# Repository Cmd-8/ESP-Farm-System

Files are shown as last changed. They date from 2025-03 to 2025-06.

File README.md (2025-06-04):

# ESP-Farm-System
Auto Farming System ESP-32

Read "ESP Auto Greenhouse Farm.pdf" for more detail

STL models for 3D printing 

Summary: 
This system is designed to automate watering, lighting, and sensor data collection 
for household or small community greenhouse farming. It can be easily monitored 
and controlled through any internet-connected device. Powered by four ESP-32 
devices, the system collects environmental data, processes it using moving 
averages and low-pass filters for accuracy, and sends this data to other devices to 
activate watering and lighting systems as needed. Users can customize the 
frequency of data collection, ranging from once a day to every 15 minutes, 
optimizing power usage based on plant care needs. The data is sent to Adafruit IO 
which graphs all data, this can be analyzed and be used to improve the system 
itself.  
  
The system includes four key ESP-32 units. SS.ESP handles sensor data collection 
and sends it to the rest of the system. H.ESP activates the watering system based 
on sensor readings, ensuring plants receive the correct amount of water. L.ESP 
manages the lighting system, providing the lights turn on at a fixed time each day. 
Sunflower tracks the sun's position by adjusting its motor to align with the azimuth 
and elevation of the sun, using monthly average data from a sun-tracking website. 
This feature makes the system self-sufficient. The 3D model design of sunflower 
has leaves sticking out from the stem similar to an actual sunflower.

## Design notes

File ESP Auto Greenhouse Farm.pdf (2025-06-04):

# E-Farm

## Summary:

This system is designed to automate watering, lighting, and sensor data collection for household or small community greenhouse farming. It can be easily monitored and controlled through any internet-connected device. Powered by four ESP-32 devices, the system collects environmental data, processes it using moving averages and low-pass filters for accuracy, and sends this data to other devices to activate watering and lighting systems as needed. Users can customize the frequency of data collection, ranging from once a day to every 15 minutes, optimizing power usage based on plant care needs. The data is sent to Adafruit IO which graphs all data, this can be analyzed and be used to improve the system itself.

The system includes four key ESP-32 units. SS.ESP handles sensor data collection and sends it to the rest of the system. H.ESP activates the watering system based on sensor readings, ensuring plants receive the correct amount of water. L.ESP manages the lighting system, providing the lights turn on at a fixed time each day. Sunflower tracks the sun's position by adjusting its motor to align with the azimuth and elevation of the sun, using monthly average data from a sun-tracking website. This feature makes the system self-sufficient. The 3D model design of sunflower has leaves sticking out from the stem similar to an actual sunflower.

Links
Code: https://github.com/Cmd-8/ESP-Farm-System
YouTube: www.youtube.com/@Cmd.8

## Parts:

4x ESP-32
1x BME280
2-5x Capacitive soil moisture sensor
1-2x Relay Module
1x Peristaltic Liquid Pump or 1x Plastic Water Solenoid Valve 1x l298n motor driver
1x Solar panel
2x waterproof Nema 17 or 23 motor
1x Power station or some form of power system 1x CNC Sheild and 2x DRV8825

## Method:

I will provide a tutorial video for all the customizing for all the different systems.

The case design for components should not be used exclusively for outdoor environments and must include additional protection. For example, a box to put the electronics in can be used alongside the case design to safeguard the components. The case design is intended for indoor use within a greenhouse, ideally placed in an elevated location. Users should be aware that thicker walls or certain materials may interfere with data transmission. 3D printed cases or parts should be using ASA material, as it provides heat and UV protection, preventing warping due to temperature changes or UV exposure.

When setting up the soil sensor, it is recommended to use larger sections of soil rather than multiple smaller ones for vegetables, maximizing the use of one sensor per type of vegetable. This approach works well because soil moisture doesn’t fluctuate significantly over short distances unless physically separated.

The water pump can source water from a rainwater recycling system or use a water valve. A relay or motor driver can be used to control the valve or pump, with a relay being the preferred option for this application. Set up a cup to measure how much water it gets for each timer setting.

To set up Adafruit, you must create an account with Adafruit, which will provide an API key. This key should be written into the code where specified. Wi-Fi information should also be configured, as outlined in the code. Both L.ESP and SS.ESP require both Adafruit and Wi-Fi connections, while H.ESP only requires Wi-Fi. S.ESP and H.ESP must have the same interval time to sync together. For example:

#define TIME_TO_SLEEP 900

This value represents 15 minutes in seconds. After the data is taken, the system will enter deep sleep for 15 minutes before repeating the process. Both must use the same value to remain synchronized.

The Sunflower system has a weight limit of 3.0 lbs for the solar panel from the X-motor. Users can obtain the sun path for their location from a website and average the monthly data. The code is designed for easy customization, allowing users to adjust settings as needed. 3D scanning the leaves and features on sunflowers can provide for a more realistic look!

L.ESP can be used with full spectrum light bulbs for additional light in seasons where there’s not a lot of sunlight, this allows vegetables to grow all year round. It uses a relay switch that enables and disables current flow to light bulbs. Light bulbs should be in parallel cause the light bulb in series will cause the voltage to go over the relay limit instead use parallel for amperes, the limit being 10A and I got around 4/6 light bulbs with it.

## Electrical Use:

The average cost for electrical power is 1kilowatts for $0.14.
The running time for SS.ESP is 1-2 milliseconds with ~600 milliamps/hour but deep-sleep uses 5-10 microamps, and always 5 volts.
H.ESP and L.ESP use around ~300 milliamps/hour when activated and the same deep sleep power consumption.

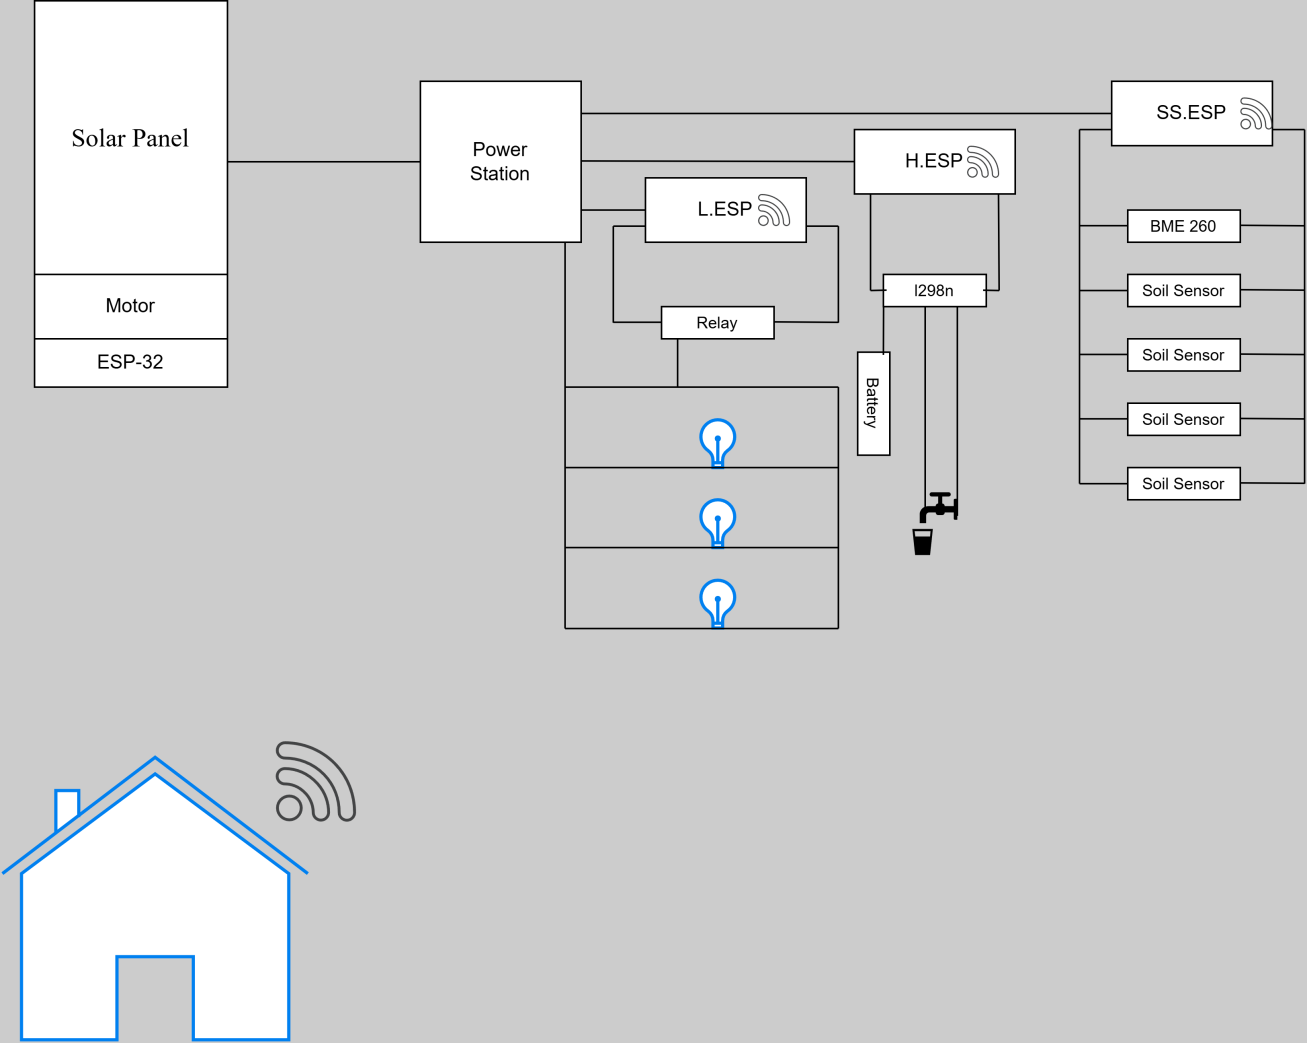
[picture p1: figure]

## Technical:

Communication between ESP-32 devices utilizes the ESP-NOW protocol, which relies on the MAC address of each device. It ensures 100% data transmission up to 220 meters, though it can extend to 1,000 meters with some data loss. The ESP data filter processes 10 sensor readings, averages them and applies a low-pass filter before sending the data. For more accurate results, you can increase the sample rate beyond 10 and adjust the low-pass filter by modifying the alpha value (0 < a < 1). Additional improvements can be made by using a hardware low-pass filter, applying EMI protection to the wires, and using an external 16-bit ADC for sensors.

Adafruit IO allows up to 30 data points per minute and 10 feeds (e.g., "Temperature feed") in the free version. The paid version increases this to 60 data points per minute and offers unlimited feeds, making it suitable for large-scale greenhouse farming. Adafruit also provides a graphical interface to display the data, enabling users to analyze trends and make improvements, which contributes to the system's self-improvement over time.

The sensors and lights are connected in parallel due to the low current draw of each device. Each relay typically supports a maximum load of AC 250V / 10A or DC 30V / 10A and can be used with 4-6 full-spectrum lights that promote plant growth. Capacitive soil sensors are preferred due to their reliability compared to other types that may rust over time. However, the exposed electronics on the top of the sensor should be protected with a 3D-printed case for enhanced durability.

The water valve can be powered by a power station or an external source such as a battery. The ESP-32 receives soil moisture data through the ESP-NOW protocol and can be customized to control watering based on specific plant requirements, using a timer (e.g., `Delay(1000)`).

The Sunflower system uses two waterproof Nema 17 stepper motors and a CNC Shield with two DRV8825 drivers. The power supply is 12/24V ~3A, which can be connected to an outlet, power station, or external battery. The Sunflower system activates every hour to move the two motors, with the X-motor adjusting the azimuth and the Y-motor controlling the elevation. The data averages the sun's position for azimuth and elevation each month. The system's accuracy has an error range of ±1.8 degrees, as each step is 1.8 degrees, and the stepper motor only moves in whole steps, rounding the values during calculation.

The weight limit for the solar panel on the X-motor is 3.0 lbs, lighter panels reduce power consumption, as less torque is required to move the panel. Lower torque means less current is needed to move the motor. To accommodate a heavier solar panel, the acceleration and speed can be adjusted to provide more torque.

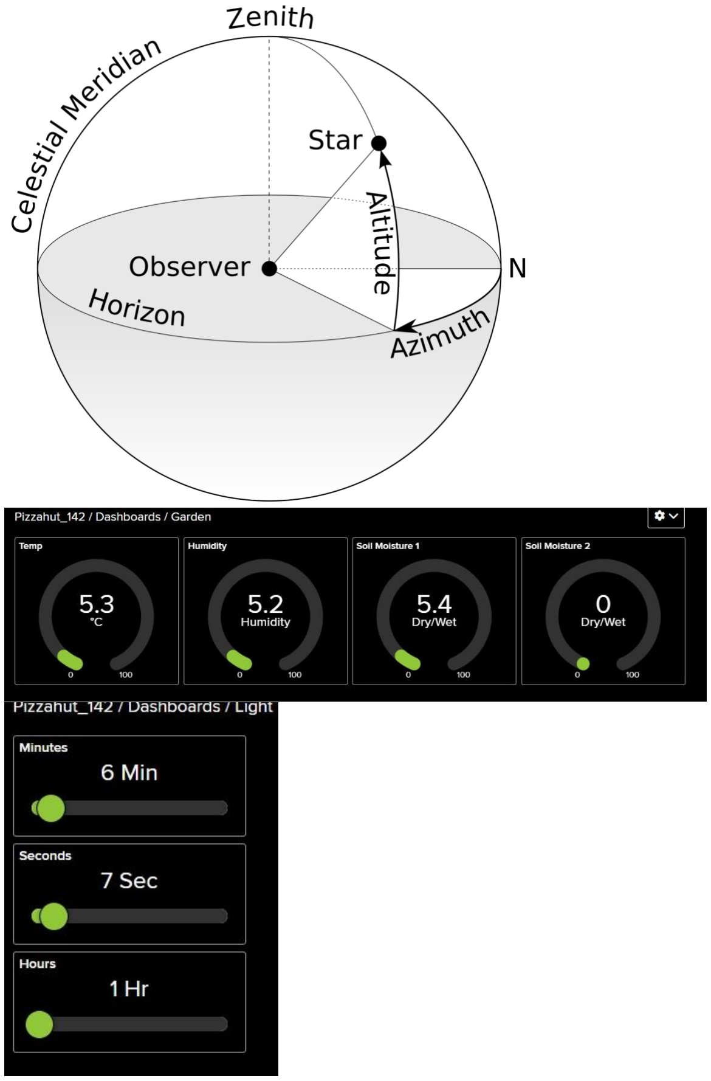
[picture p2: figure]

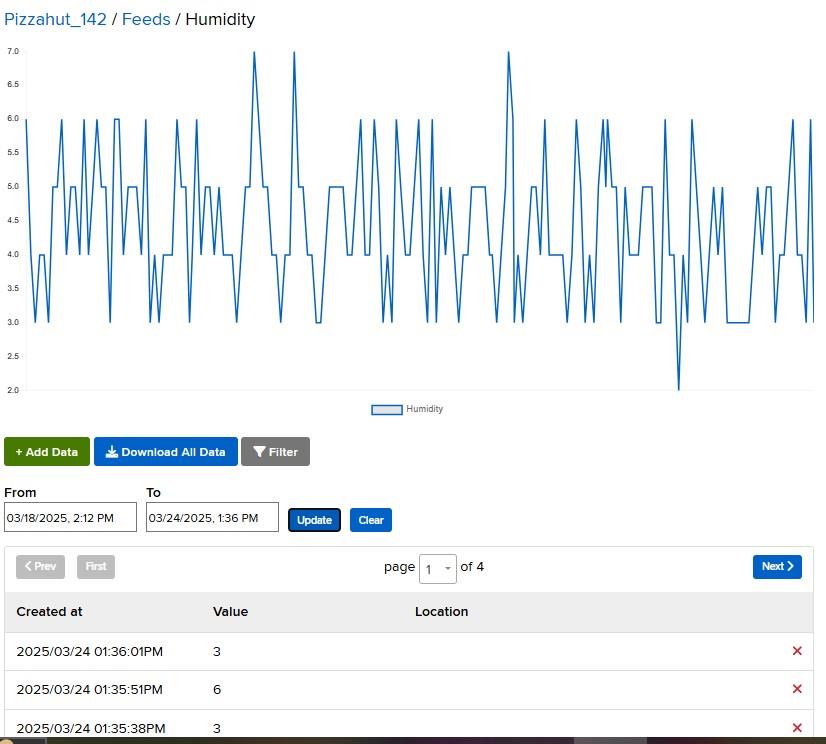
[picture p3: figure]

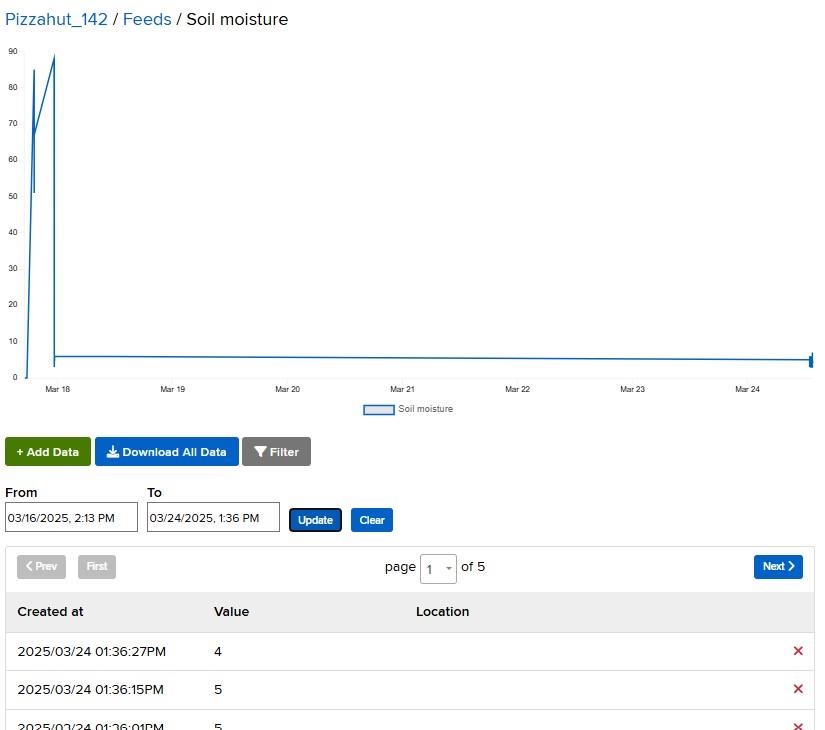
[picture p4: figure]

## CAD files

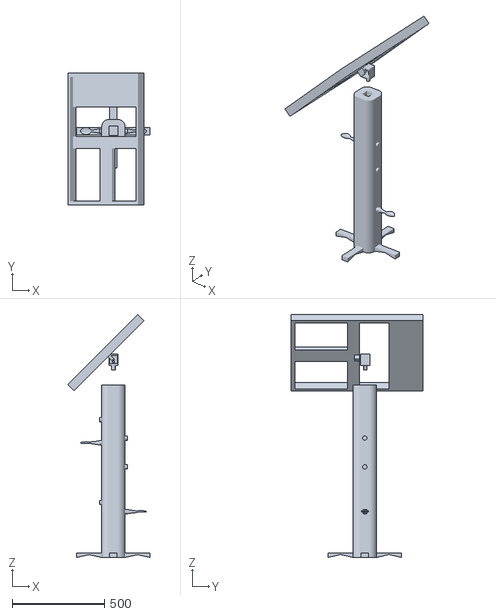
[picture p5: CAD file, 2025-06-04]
SunFlower Full_.stl
448.0 x 717.1 x 1320.3

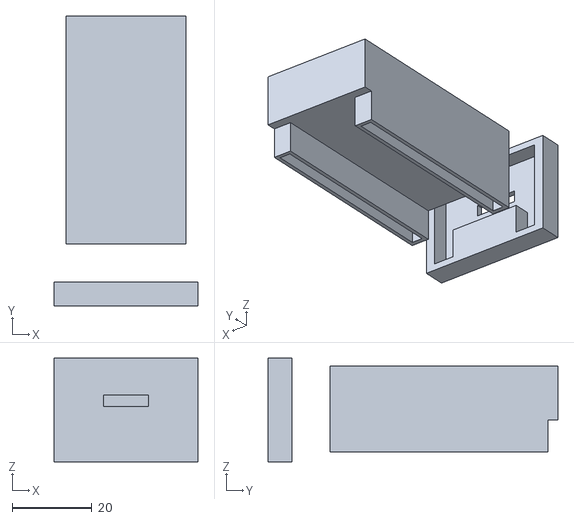
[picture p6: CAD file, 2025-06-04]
Esp-32 Full Case_.stl
36.0 x 72.4 x 26.0

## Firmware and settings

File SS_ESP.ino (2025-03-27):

/*
MAKE SURE TO ADD THIS IN YOUR ADDTIONAL BOARD MANAGER URL IF NEVER USED AN ESP 32 
FILE--->PREFENCES--->SETTINGS
https://dl.espressif.com/dl/package_esp32_index.json
https://raw.githubusercontent.com/espressif/arduino-esp32/gh-pages/package_esp32_index.json

_____________________________________________________________________________________________
Imported library need for this project, make sure to download all the libraries before using (On the left side tabs)

*BOARD MANAGER INSTALL*
-esp32 by Espressif Systems

------------------------------------------
*LIBRARY MANAGER INTSTALL*
-Adafruit BME280 by Adafruit
-Adafruit BusIO by  Adafruit
-Adafuit IO Arduino by Adafruit
-Adafruit MQTT by Adafruit
*/
//_________________________________________________________________________________________________________________________________________________________________________________________________

#include <SPI.h>
#include <Adafruit_Sensor.h>
#include <Adafruit_BME280.h>
#include <esp_now.h>
#include <WiFi.h>
#include <esp_wifi.h>
#include <Adafruit_MQTT.h>            
#include <Adafruit_MQTT_Client.h>     

//--------------------------------------------------------------------------------
//PLUG IN YOU INFROMATION HERE " --HERE-- "

// Configuration of wifi and adafruit
#define WIFI_SSID "WIFI"                //<--- " --HERE-- "
#define WIFI_PASS "PASSWORD"            //<--- " --HERE-- "
#define AIO_SERVER "io.adafruit.com"
#define AIO_SERVERPORT 1883
#define AIO_USERNAME "USERNAME"         //<--- " --HERE-- "
#define AIO_KEY "API KEY"               //<--- " --HERE-- "

//--------------------------------------------------------------------------------
//TIME_TO_SLEEP IS HOW OFTEN YOU WANT DATA RO BE TAKEN
//3600 = 1 HR   7200 = 2 HR       1800 = 30 MINS      900 = 15 MINS
//DO 10 FOR TESTING (10 SECONDS) 

//The sleep configraution for how long it goes to power sbaing mode (deep-sleep)
#define uS_TO_S_FACTOR 1000000ULL     //conversion from microseconds to seconds 
#define TIME_TO_SLEEP 900             //THIS DEFAULT AT 15 MINUTES  
#define MAX_RETRIES 5                 //connection retries
#define RETRY_DELAY 500               //ms between retries
//--------------------------------------------------------------------------------

//ULL is unsignes long long which allowes to sleep longer than 32 minutes max, the longest max known would be 48 hours 

//--------------------------------------------------------------------------------
//YOU CAN CHANGE THE PIN ANY OF THESE IF YOU WANT 
//THIS WHERE THE NUMBER PIN ON ESP-32 YOU WOULD CONNECT

// SPI pins for BME280
#define BME_CS    5       // Chip select pin for SPI
#define BME_SCK   18      // Clock pin
#define BME_MISO  19      // MISO pin
#define BME_MOSI  23      // MOSI pin

Adafruit_BME280 bme;  // Create an instance of the BME280 sensor

// Soil sensor analog pins
const int soilSensor1Pin = 32;
const int soilSensor2Pin = 35;
const int soilSensor3Pin = 34;
const int soilSensor4Pin = 36;
//--------------------------------------------------------------------------------

//_________________________________________________________________________________________________________________________________________________________________________________________________
//PLEASE PUT YOUR INFORMATION INTO THE RIGHT FEEDS

//USED to send data for adadruit which is connceted to the feed you made in it
// MQTT Client
WiFiClient client;
Adafruit_MQTT_Client mqtt(&client, AIO_SERVER, AIO_SERVERPORT, AIO_USERNAME, AIO_KEY);

//*MQTT Feeds*
Adafruit_MQTT_Publish humidityFeed = Adafruit_MQTT_Publish(&mqtt, AIO_USERNAME "/feeds/humidity");
Adafruit_MQTT_Publish soilMoistureFeed = Adafruit_MQTT_Publish(&mqtt, AIO_USERNAME "/feeds/soil-moisture");
Adafruit_MQTT_Publish temperatureFeed = Adafruit_MQTT_Publish(&mqtt, AIO_USERNAME "/feeds/temperature");

//_________________________________________________________________________________________________________________________________________________________________________________________________

// Parameters for averaging and low-pass filter
const int numSamples = 10;  // Number of samples to take for each sensor
float alpha = 0.1;           // Smoothing factor for low-pass filter CAN EDIT TO BE FROM 0.1 - .9

// Arrays for storing readings
float temperatureSamples[numSamples];
float humiditySamples[numSamples];
float pressureSamples[numSamples];
int soilMoistureSamples[4][numSamples];

// Variables to store filtered data
float filteredTemperature = 0;
float filteredHumidity = 0;
float filteredPressure = 0;
float smoothedSoilMoisture[4] = {0.0, 0.0, 0.0, 0.0};

// Summing variables for averaging
long tempSum = 0;
long humSum = 0;
long pressSum = 0;
long soilSum[4] = {0, 0, 0, 0};

int sampleIndex = 0;
bool dataCollected = false;

RTC_DATA_ATTR unsigned int bootCount = 0;
volatile bool dataSent = false;

//_________________________________________________________________________________________________________________________________________________________________________________________________
//This section includes all the other congfigurations for adafruit and esp-now protocol, like cheching for connection and confirmation on data being sent 

// REPLACE WITH YOUR RECEIVER MAC ADDRESSES
uint8_t broadcastAddress1[] = {0x  , 0x  , 0x  , 0x  , 0x  , 0x  };  //{0x3C, 0xBC, 0xBB, 0x06, 0x38, 0xB0};


// Struct for sensor data transmission THIS MUST MATCH WITH THE OTHER ESP-32
//---------------------------------------------------------------------------
typedef struct __attribute__((packed)) SensorData {
  int16_t airTemp;
  uint8_t airHum;
  uint8_t soilMoist;
  uint8_t power;
} SensorData;

SensorData sensorData;
esp_now_peer_info_t peerInfo;
//---------------------------------------------------------------------------


// MQTT Connection Function
void connectToAdafruitIO() {
  Serial.println("Connecting to Adafruit IO...");
  
  // Connect to WiFi
  WiFi.begin(WIFI_SSID, WIFI_PASS);
  while (WiFi.status() != WL_CONNECTED) {
    delay(500);
    Serial.print(".");
  }
  Serial.println("\nWiFi connected!");

  // Get and print WiFi channel
  int currentChannel = WiFi.channel();
  Serial.print("Current WiFi Channel: ");
  Serial.println(currentChannel);

  // Connect to MQTT
  int8_t ret;
  while ((ret = mqtt.connect()) != 0) {
    Serial.println("Retrying MQTT connection in 5 seconds...");
    mqtt.disconnect();
    delay(5000);
  }
  Serial.println("Adafruit IO Connected!");
}


// MQTT Publish Function
bool publishToAdafruitIO() {
  // Ensure MQTT connection
  if (!mqtt.connected()) {
    connectToAdafruitIO();
  }

  // Publish sensor data
  bool publishSuccess = true;
  
  publishSuccess &= temperatureFeed.publish(filteredTemperature);
  publishSuccess &= humidityFeed.publish(filteredHumidity);
  publishSuccess &= soilMoistureFeed.publish(smoothedSoilMoisture[1]);

  if (publishSuccess) {
    Serial.println("Data published successfully to Adafruit IO!");
    return true;
  } else {
    Serial.println("Failed to publish data to Adafruit IO.");
    return false;
  }
}


// ESP-NOW Peer Addition Function
bool addPeer(const uint8_t* peerAddr) {
  memset(&peerInfo, 0, sizeof(peerInfo));
  
  // Use the current WiFi channel
  peerInfo.channel = WiFi.channel();
  peerInfo.encrypt = false;
  memcpy(peerInfo.peer_addr, peerAddr, 6);
  
  esp_err_t result = esp_now_add_peer(&peerInfo);
  switch(result) {
    case ESP_OK:
      Serial.printf("Peer added successfully: %02x:%02x:%02x:%02x:%02x:%02x\n",
                    peerAddr[0], peerAddr[1], peerAddr[2], 
                    peerAddr[3], peerAddr[4], peerAddr[5]);
      return true;
    case ESP_ERR_ESPNOW_NOT_INIT:
      Serial.println("ESP-NOW not initialized");
      break;
    case ESP_ERR_ESPNOW_ARG:
      Serial.println("Invalid argument");
      break;
    case ESP_ERR_ESPNOW_FULL:
      Serial.println("Peer list full");
      break;
    default:
      Serial.printf("Unknown error: %d\n", result);
  }
  return false;
}


// ESP-NOW Send Callback
void OnDataSent(const uint8_t *mac_addr, esp_now_send_status_t status) {
  char macStr[18];
  snprintf(macStr, sizeof(macStr), "%02x:%02x:%02x:%02x:%02x:%02x",
           mac_addr[0], mac_addr[1], mac_addr[2], mac_addr[3], mac_addr[4], mac_addr[5]);
  
  Serial.printf("Sent to %s - Status: %s\n", 
                macStr,
                status == ESP_NOW_SEND_SUCCESS ? "Success" : "Fail");
  dataSent = (status == ESP_NOW_SEND_SUCCESS);
}

// Send Data to Specific Device
bool sendData(const uint8_t* targetAddress, const SensorData& data) {
    int retryCount = 0;
    bool success = false;
    
    while (retryCount < MAX_RETRIES && !success) {
        dataSent = false;
        Serial.printf("Sending to %02X:%02X:%02X:%02X:%02X:%02X - Attempt %d of %d\n",
                     targetAddress[0], targetAddress[1], targetAddress[2],
                     targetAddress[3], targetAddress[4], targetAddress[5],
                     retryCount + 1, MAX_RETRIES);
        
        // Ensure we're on the correct channel before sending
        esp_wifi_set_channel(WiFi.channel(), WIFI_SECOND_CHAN_NONE);
        
        esp_err_t result = esp_now_send(targetAddress, (uint8_t*)&data, sizeof(data));
        
        if (result != ESP_OK) {
            Serial.println("Send Init Failed");
            retryCount++;
            delay(RETRY_DELAY);
            continue;
        }
        
        // Wait for callback with timeout
        unsigned long start = millis();
        while (!dataSent && (millis() - start) < 1000) {
            delay(10);
        }
        
        if (dataSent) {
            success = true;
            Serial.println("Data sent successfully");
            break;
        } else {
            Serial.println("Send timeout or failed");
            retryCount++;
            delay(RETRY_DELAY);
        }
    }
    return success;
}

//_________________________________________________________________________________________________________________________________________________________________________________________________
//This sections brings it all together and actually what runs

void setup() {
  int Timer = micros();                 //Timer 
  Serial.begin(115200);                 //Allow communcation through usb with the PC
  WiFi.setTxPower(WIFI_POWER_15dBm);    //This to increase wifi range of esp-32 
  btStop();                             //Turn off bluetooth to save power 

  // Initialize SPI and BME280 sensor
  SPI.begin(BME_SCK, BME_MISO, BME_MOSI, BME_CS);
  if (!bme.begin()) {
    Serial.println("Could not find a valid BME280 sensor, check wiring!");
    while (1); // Stop if sensor is not found
  }

//---------------------------------------------------------------------------------------------------------------------  
//THIS WHERE THE CALCULTAIONS FOR MOVING AVERAGE AND LOW PASS FILTER IS ADD TO SENSOR DATA
  
  // Collect 10 samples for each sensor
  while (!dataCollected) {
    // --- Collecting Data from BME280 ---  To test do random(0, 100); instead of bme.read
    float temp = bme.readTemperature();                                 //random(0, 100);
    float humidity = bme.readHumidity();                                //random(0, 100);
    float pressure = bme.readPressure() / 100.0F;  // Pressure in hPa   //random(0, 100);

    // Store the raw readings
    temperatureSamples[sampleIndex] = temp;
    humiditySamples[sampleIndex] = humidity;
    pressureSamples[sampleIndex] = pressure;
    
    /*
    for (int i = 0; i < 4; i++) {
      soilMoistureSamples[i][sampleIndex] = random(0,100);  // Analog pins A0, A1, A2, A3 for soil sensors
    }
    */
    
    // Collect soil moisture readings
    for (int i = 0; i < 4; i++) {
      soilMoistureSamples[i][sampleIndex] = analogRead(i + A0);  // Analog pins A0, A1, A2, A3 for soil sensors
    }
    
    sampleIndex++;  // Move to the next sample index

    // When all samples are collected, set the flag
    if (sampleIndex >= numSamples) {
      dataCollected = true;
    }

    // Delay between readings
    delay(100);  // 100ms delay
  }

  // Process and average the 10 samples
  for (int i = 0; i < numSamples; i++) {
    tempSum += temperatureSamples[i];
    humSum += humiditySamples[i];
    pressSum += pressureSamples[i];

    for (int j = 0; j < 4; j++) {
      soilSum[j] += soilMoistureSamples[j][i];
    }
  }

  // Calculate the averages for each sensor
  float avgTemperature = tempSum / numSamples;
  float avgHumidity = humSum / numSamples;
  float avgPressure = pressSum / numSamples;

  // Apply Low-Pass Filter
  filteredTemperature = (alpha * avgTemperature) + (1 - alpha) * filteredTemperature;
  filteredHumidity = (alpha * avgHumidity) + (1 - alpha) * filteredHumidity;
  filteredPressure = (alpha * avgPressure) + (1 - alpha) * filteredPressure;

  for (int i = 0; i < 4; i++) {
    float avgSoilMoisture = soilSum[i] / numSamples;
    smoothedSoilMoisture[i] = (alpha * avgSoilMoisture) + (1 - alpha) * smoothedSoilMoisture[i];
  }

  // Print soil sensor readings
  for (int i = 0; i < 4; i++) {
    Serial.print("Soil Sensor "); Serial.print(i+1); Serial.print(": ");
    Serial.print(smoothedSoilMoisture[i]); Serial.println(" %");
  }

//---------------------------------------------------------------------------------------------------------------------  

  // WiFi and ESP-NOW Setup
  WiFi.mode(WIFI_STA);
  int currentChannel = WiFi.channel();
  esp_wifi_set_channel(currentChannel, WIFI_SECOND_CHAN_NONE);
  
  // Connect to Adafruit IO
  connectToAdafruitIO();

  // Publish data to Adafruit IO
  publishToAdafruitIO();
  
  // Initialize ESP-NOW
  if (esp_now_init() != ESP_OK) {
    Serial.println("ESP-NOW Init Failed");
    esp_deep_sleep_start();
    return;
  }
  
  esp_now_register_send_cb(OnDataSent);
  
  // Add peers
  bool peer1Added = addPeer(broadcastAddress1);
  
  if (!peer1Added) {
    Serial.println("No peers added successfully. Entering sleep.");
    esp_deep_sleep_start();
    return;
  }
  
  // Map soil moisture values
  for (int i = 0; i < 4; i++) {
    smoothedSoilMoisture[i] = map(smoothedSoilMoisture[i], 0, 4096, 0, 100);
  }

  // Prepare sensor data
  sensorData.airTemp = filteredTemperature * 100;  // Multiply by 100 for precision
  sensorData.airHum = filteredHumidity;
  sensorData.soilMoist = smoothedSoilMoisture[1]; // Using first soil moisture sensor
  sensorData.power = 1;  // Battery percentage or power status
  
  // Send to device
  bool device1Success = sendData(broadcastAddress1, sensorData);
  
  // Log results
  Serial.printf("Device 1 send %s\n", device1Success ? "successful" : "failed");

  // Sleep configuration
  esp_sleep_enable_timer_wakeup(TIME_TO_SLEEP * uS_TO_S_FACTOR);
  Serial.flush();
  delay(100);
  esp_deep_sleep_start();
}

void loop() {
  // No need to loop; data is collected and processed only once in setup
}

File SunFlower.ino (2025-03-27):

/*
MAKE SURE TO ADD THIS IN YOUR ADDTIONAL BOARD MANAGER URL IF NEVER USED AN ESP 32 
FILE--->PREFENCES--->SETTINGS
https://dl.espressif.com/dl/package_esp32_index.json
https://raw.githubusercontent.com/espressif/arduino-esp32/gh-pages/package_esp32_index.json

_____________________________________________________________________________________________
Imported library need for this project, make sure to download all the libraries before using (On the left side tabs)

*BOARD MANAGER INSTALL*
-esp32 by Espressif Systems

------------------------------------------
*LIBRARY MANAGER INTSTALL*
-AccelStepper by Mike

--------------------------------------------
#include Month.h imports a class made in the second file called "Month.h" 
*/
//_________________________________________________________________________________________________________________________________________________________________________________________________

#include "Month.h"
#include "Arduino.h"
#include <WiFi.h>
#include <Stepper.h>
#undef OCT
#undef DEC

#define uS_TO_S_FACTOR 1000000ULL  /* Conversion factor for micro seconds to seconds */
#define inverteral_TIME 3600  // 1 hour

//------------------------------------------------------------------------
//You can change the numbers depending on your motor
// Motor Step Constants
const float A_motor_step = 1.8;       //This motor moves 1.8 degrees every step
const byte ledPin = 2; // Replace with your chosen GPIO pin
const int stepsPerRevolution = 200;   //Won't be used 

//------------------------------------------------------------------------
RTC_DATA_ATTR int day = 0;  // Day counter, starts from 0
RTC_DATA_ATTR int timer = 0; // Timer counter, starts from 0

// Define pins for stepper motors
const int motorX_pin1 = 5;  // Set the GPIO pins for Stepper Motor X
const int motorX_pin2 = 18; 
const int motorY_pin1 = 19; // Set the GPIO pins for Stepper Motor Y
const int motorY_pin2 = 21;

// Create Stepper motor objects
Stepper myStepperX(stepsPerRevolution, motorX_pin1, motorX_pin2);
Stepper myStepperY(stepsPerRevolution, motorY_pin1, motorY_pin2);

//_________________________________________________________________________________________________________________________________________________________________________________________________
//HERE'S WHERE YOU CAN PUT YOUR DATA FOR EACH MONTH INTO 
//ROUNDING TO EVEN NUMBER MADE EASIER FOR THE MOTOR-Y TO MOVE BACK TO ORGIN (0)
//------------------------------------------------------------
// Define Months with sunrise, sunset, and hours of daylight
Month JAN(12, 31, 12, 123.6 , 240.3, 29.7);
Month FEB(14, 59, 10, 116.8 , 245.1, 45.2);
Month MAR(16, 90, 8, 100.3 , 251.9, 58.1);      // 15 round up to 16
Month APR(18, 120, 7, 90.5 , 260.4, 68.3);      // 17 round uo to 18
Month MAY(18, 151, 6, 80.2 , 268.7, 73.8);
Month JUNE(18, 181, 6, 70.1 , 275.9, 76.5);
Month JULY(18, 212, 6, 72.3 , 270.5, 75.2);
Month AUG(16, 243, 8, 85.6, 261.8, 69.4);
Month SEP(16, 273, 8, 98.7, 254.2, 60.7);       // 15 round up to 16
Month OCT(14, 304, 10, 112.4, 247.6, 50.9);
Month NOV(12, 334, 12, 111.56, 248.85, 36.10);
Month DEC(8, 365, 16, 125.32, 232.59, 28.73);
//----------------------------------------------------------------------------------------------------------------------

//THIS DOES THE MATH AND ROUND THE NUMBER TO WHOLE A NUMBER FOR THE STEPS
//THE ERROR IS +- 1.8 DEGREES FOR SUN-SET OR SUNRSIE  
// Stepper Motor Arrays
//This was used to round to get rid of decimal cause motor can't move fractions of step
const byte Peak[12] = {(JAN.hours / 2), (FEB.hours / 2), (MAR.hours / 2), (APR.hours / 2), (MAY.hours / 2), 
                        (JUNE.hours / 2), (JULY.hours / 2), (AUG.hours / 2), (SEP.hours / 2), (OCT.hours / 2),
                        (NOV.hours / 2), (DEC.hours / 2)};

const byte Set_Array[12] = {((JAN.Set - JAN.Rise) / A_motor_step), ((FEB.Set - FEB.Rise) / A_motor_step), 
                            ((MAR.Set - MAR.Rise) / A_motor_step), ((APR.Set - APR.Rise) / A_motor_step), 
                            ((MAY.Set - MAY.Rise) / A_motor_step), ((MAY.Set - MAY.Rise) / A_motor_step),
                            ((JUNE.Set - JUNE.Rise) / A_motor_step), ((JULY.Set - JULY.Rise) / A_motor_step), 
                            ((AUG.Set - AUG.Rise) / A_motor_step), ((SEP.Set - SEP.Rise) / A_motor_step), 
                            ((OCT.Set - OCT.Rise) / A_motor_step), ((NOV.Set - NOV.Rise) / A_motor_step)};

//_________________________________________________________________________________________________________________________________________________________________________________________________

//FUNCTIONS THAT HANDLES THE MOVEMENT 
// Function to move motors to position
void moveMotorToPosition(float position, int motor) {
  Serial.print("Moving motor ");
  Serial.print(motor);
  Serial.print(" to position: ");
  Serial.println(position);
  
  if (motor == 1) {
    myStepperX.step(position);  // Move motor X
  } else if (motor == 2) {
    myStepperY.step(position);  // Move motor Y
  }
}

// Function to handle motor movements based on the current month and timer
void handleMonthMovement(Month month, int monthIndex) {
  if (timer == 0) {
    Serial.println("Moving Motors to origin");
    moveMotorToPosition(month.Rise, 1);  // Example for motor 1
    moveMotorToPosition(0, 2);  // Example for motor 2
    timer++;
  } else if (timer > 0 && timer < month.hours) {
    timer++;
    Serial.println("Moving Motor X");
    moveMotorToPosition(Set_Array[monthIndex] / month.hours, 1);  // Adjust for each motor
    if (timer < Peak[monthIndex] || timer == Peak[monthIndex]) {
      Serial.println("Moving Motor Y");
      moveMotorToPosition((month.Elevation- 45) / month.hours, 2);  // Adjust for each motor  MINUS BY 45 ANGLE OF SOLAR PANEL
    } else {
      Serial.println("Moving Motor Y back");
      moveMotorToPosition(-((month.Elevation -45) / month.hours), 2);  // Adjust for each motor
    }
  } else if (timer == month.hours) {
    timer = 0;
    day++;
    Serial.println("Moving Motor X to origin");
    moveMotorToPosition(0, 1);  // Return motor to origin
    esp_sleep_enable_timer_wakeup(month.sleep * uS_TO_S_FACTOR);
    esp_deep_sleep_start();
  }
}
//_________________________________________________________________________________________________________________________________________________________________________________________________
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
